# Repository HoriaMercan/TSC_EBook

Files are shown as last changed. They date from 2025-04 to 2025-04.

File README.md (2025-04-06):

## Horia Mercan - OpenBook - Systems Testing

This project presents the electronic design (schematic/pcb) and the visual design of a complete ebook. 

## Hardware Modules and Components

**ESP32-C6-WROOM-1-N8 – Main Microcontroller:**
* Power Supply: 3.3V.
* Communications: SPI, I2C, UART, GPIO.

We will link interfaces of each module with main controller's pins:

**SPI ESD Protection Lines**
* Protects the SPI lines for the SD card, e-paper, external flash.

**LDO Voltage Regulator**
* Steps down the voltage from 5V to 3.3V to power the ESP32-C6 and other modules.

**SD Card Module**
* Interface: SPI
* Pins Used:
    * `SS_SD` → `IO4`
    * `MOSI` → `IO7`
    * `MISO` → `IO2`
    * `SCK` → `IO6`

**E-Paper Display**
* Interface: SPI
* Pins Used:
    * `EPD_CS` → `IO10`
    * `EPD_DC` → `IO5`
    * `EPD_RST` → `IO23`
    * `EPD_BUSY` → `IO3`
    * `MOSI`, `SCK` (shared with SD)

**RTC Module - DS3231SN**
* Interface: I2C
* Pins Used:
    * `SCL` → `IO22`
    * `SDA` → `IO21`
    * `INT_RTC` → `IO8`
    * `32KHZ` → `IO1`
    * `RTC_RST` → `IO18`

**LiPo Fuel Gauger**
* Built-in charging control.
* MAX17048G+T10
* Battery level monitoring with:
    * Battery ChargeLevel IC → I2C => `SDA`, `SCL`

**Qwiic / Stemma QT Connector**
* Communicates entirely via I2C: `SCL`/`SDA` 

**Environmental Sensor - BME688**
* Protocol: I2C (shared) => `SDA`, `SCL`

**Environmental Sensor - BME688**
* Interface: I2C (shared with RTC)
* Power Supply: 3.3V
* Pins Used:  `SDA`, `SCL`

**External Flash - NORFlash64MB**
* Interface: SPI
* Pins Used:
    * `FLASH_CS` → `IO11`
    * Rest (`MOSI`, `MISO`, `SCK`) shared

**SD/USB interface**
* `USB_D+` → `IO13`
* `USB_D-` → `IO12`

**Reset and Boot Buttons**
* `IO/BOOT` → `IO9`
* `RESET` → `EN`

**Diodes for reverse polarity protection.**

**USB-C Connector + ESD Protection**
* Main power and data input.
* Includes TVS diodes for ESD protection.

## Block components & schematic

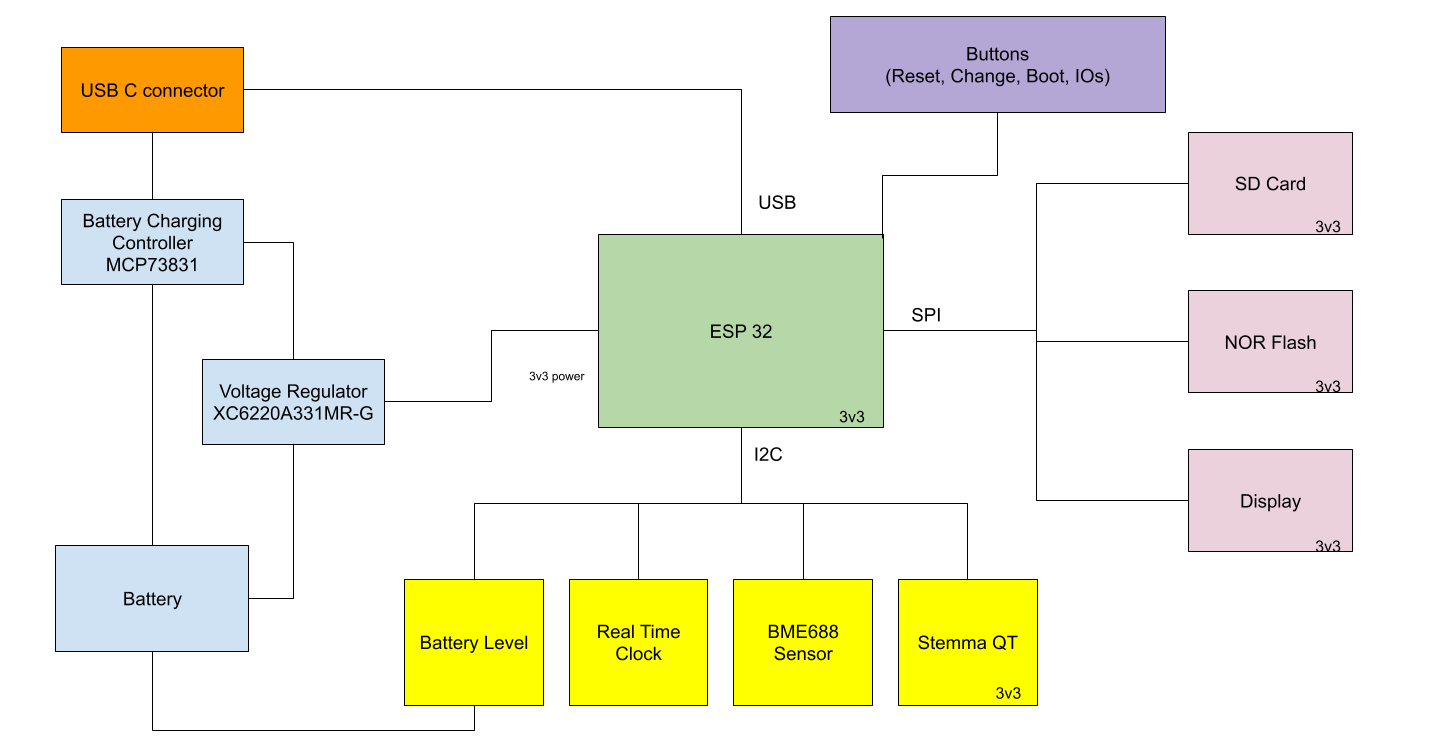
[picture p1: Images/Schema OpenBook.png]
Block functionalities and components for OpenBook


## Communication Interfaces

| Interface | Connected Components | ESP32-C6 Pins |
| :--- | :--- | :--- |
| SPI | SD Card, E-paper, NOR Flash | `MOSI` (`IO7`), `MISO` (`IO2`), `SCK` (`IO6`) |
| I2C | RTC, BME688, Battery Level | `SDA` (`IO22`), `SCL` (`IO21`) |
| UART | Debugging / Flash | `TX` (`GPIO16`), `RX` (`GPIO17`) |
| GPIO | Buttons, status signals | `IO0` - `IO23` |
| USB | PC connection / power | `USB_D+`/`D-` (`IO13`/`IO12`)

## Energy management

| Component | Power Supply (V) | Estimated Current (mA) | Estimated Power (W) | Notes |
|---|---|---|---|---|
| ESP32-C6-WROOM-1-N8 | 3.3 | 150 (average) | 0.5 | Active mode; varies significantly based on usage. |
| SD Card Module | 3.3 | 10 (average) | 0.033 | Intermittent read/write operations. |
| E-Paper Display | 3.3 | 1(average) | 0.0033 | Power used only during updates, very low average. |
| RTC Module - DS3231SN | 3.3 | 1 | 0.0033 | |
| LiPo Fuel Gauger (MAX17048) | 3.3 | 0.05 | 0.000165 | Very low power consumption. |
| BME688 (Environmental Sensor) | 3.3 | 1 (average) | 0.0033 | Intermittent readings. |
| NORFlash64MB (External Flash)| 3.3 | 2 (average) | 0.0066 | Intermittent read/write operations. |
| LDO Voltage Regulator | 5 (input) / 3.3 (output) | Variable | Variable | Efficiency depends on load; quiescent current is very low. |
| USB-C Connector + ESD | 5 (input) | Variable | Variable | Power depends on charging current; ESD protection negligible. |
| Reset/Boot Buttons | N/A | Negligible | Negligible | |
| **Total (Approximate)** | | 150-200 | **~0.55** | This is a rough estimate; actual power depends on duty cycles and usage. |

## Images

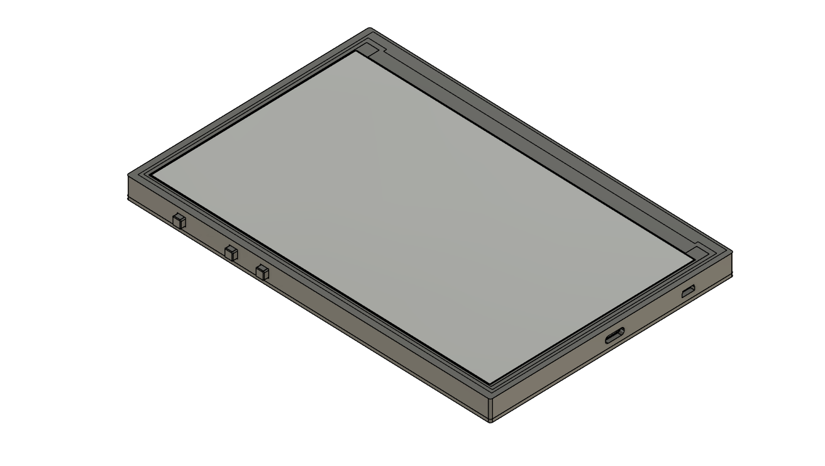
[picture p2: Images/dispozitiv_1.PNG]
Device

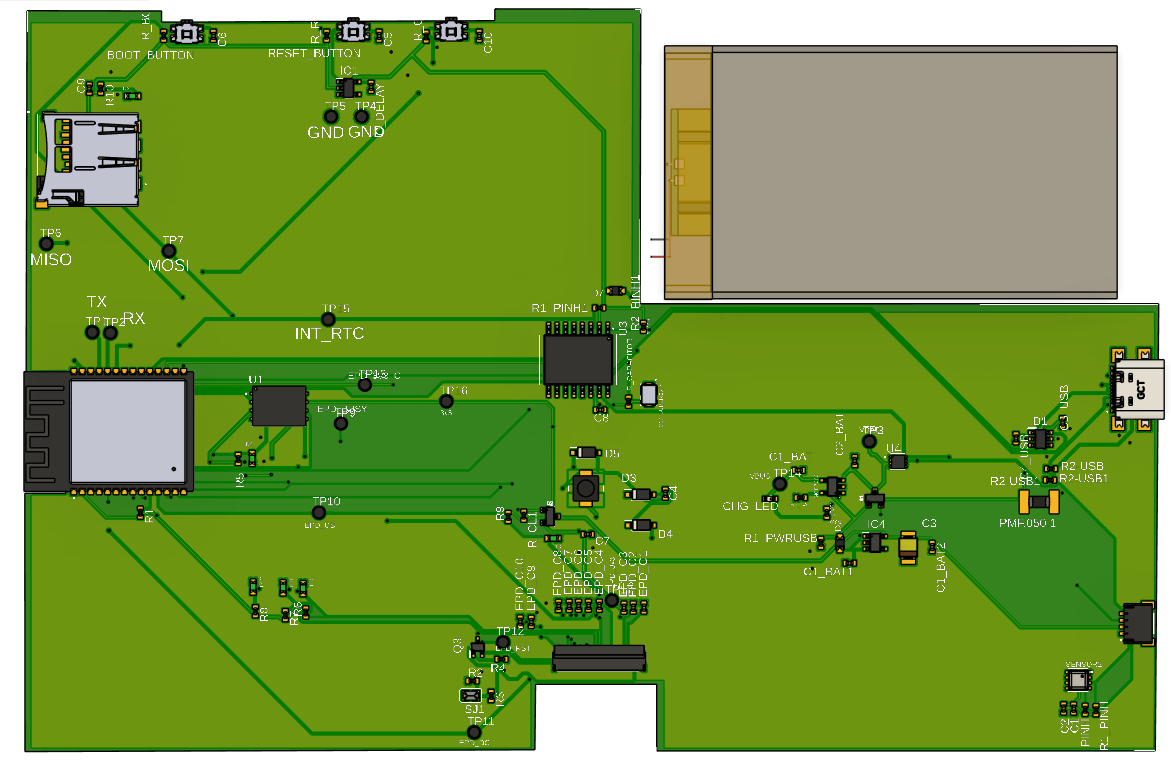
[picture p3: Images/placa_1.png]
PCB


# BOM

| Piece Name | Piece Type | Link |
|---|---|---|
| SAMACSYS_PARTS_USB4110-GF-A | USB-C Connector | https://www.snapeda.com/parts/USB4110-GF-A./Global%20Connector%20Technology/view-part/ |
| ESP32_WROVER_EAGLE-LTSPICE_R | Resistor | https://componentsearchengine.com/part-view/R0402%201%25%20100%20K%20(RC0402FR-07100KL)/YAGEO |
| MAX17048G+T10 | Cell Fuel Gauge | https://www.snapeda.com/parts/MAX17048G+T10/Analog%20Devices/view-part/ |
| W25Q512JVEIQ | Flash Memory (NOR) | https://www.snapeda.com/parts/W25Q512JVEIQ/Winbond%20Electronics/view-part/?ref=search&t=W25Q512JVEIQ |
| RCL_CPOL-EU | Polarized Capacitor | https://grabcad.com/library/tantalum-smd-capacitor-type-b-3528-1 |
| ESP32-C6-WROOM-1-N8 | ESP32 Module | https://www.snapeda.com/parts/ESP32-C6-WROOM-1-N8/Espressif%20Systems/view-part/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 |
| ADAFRUIT_CHIP-LED0603 | LED | https://www.snapeda.com/parts/KP-1608SURCK/Kingbright/view-part/?ref=search&t=LED%200603 |
| ESP32_WROVER_SPARKFUN-IC-POWER_MCP73831 | Li-Ion/Li-Poly Charge Management Controller | https://componentsearchengine.com/part-view/MCP73831T-2ACI%2FOT/Microchip |
| ESP32_WROVER_BME680_BME680 | Environmental Sensor | https://www.snapeda.com/parts/BME680/Bosch%20Sensortec/view-part/?ref=search&t=bme680 |
| CPH3225A | Crystal | https://www.snapeda.com/parts/CPH3225A/Seiko/view-part/ |
| BUTTON_CUSYOMV1 | Button | https://ro.mouser.com/ProductDetail/Panasonic/EVQ-P7L01P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. |
| FH34SRJ-24S-0.5SH_99_ | FPC Connector | https://componentsearchengine.com/part-view/FH34SRJ-24S-0.5SH(99)/Hirose |
| 744043680 | Inductor | https://eu.mouser.com/ProductDetail/Wurth-Elektronik/744043680?qs=PGXP4M47uW6VkZq%252BkzjrHA%3D%3D |
| PGB1010603MR | TVS Diode (0603) | https://www.snapeda.com/parts/PGB1010603MR/Littelfuse/view-part/ |
| SJ | 3-Way Solder Jumper | https://grabcad.com/library/solder-jumpers-1 |
| XC6220A331MR-G | Voltage Regulator | https://ro.mouser.com/ProductDetail/Torex-Semiconductor/XC6220A331MR-G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 |
| QWIIC_CONNECTOR | I²C Connector (PRT-14417) | https://www.snapeda.com/parts/PRT-14417/SparkFun/view-part/ |
| ESP32-CAP C0402 | Capacitor | https://componentsearchengine.com/part-view/CC0402MRX5R5BB106/YAGEO |
| ESP VARSISTOR | Varistor (B72520T0350K062) | https://ro.mouser.com/ProductDetail/EPCOS-TDK/B72520T0350K062?qs=dEfas%2FXlABIszF52uu7vrg%3D%3D |
| MBR0530 | Schottky Diode | https://www.snapeda.com/parts/MBR0530/Onsemi/view-part/ |
| ESP32_WROVER_SPARKFUN-DISCRETESEMI_MOSFET_PCH | MOSFET (DMG2305UX-7) | https://componentsearchengine.com/part-view/DMG2305UX-7/Diodes%20Incorporated |
| 112ATAARR03 | microSD | https://www.snapeda.com/parts/112A-TAAR-R03/Attend/view-part/ |
| ESP32_WROVER_AVX---SD0805S020S1R0 | Schottky Diode | https://componentsearchengine.com/part-view/SD0805S020S1R0/Kyocera%20AVX |
| DS3231SN# | I²C-Integrated RTC/TCXO/Crystal | https://www.snapeda.com/parts/DS3231SN%23/Analog%20Devices/view-part/?ref=search&t=DS3231SN%23 |
| BD5229G-TR | Voltage Detector | https://www.snapeda.com/parts/BD5229G-TR/Rohm/view-part/?ref=search&t=BD5229G-TR |
| SI1308EDL-T1-GE3 | MOSFET Transistor | https://www.snapeda.com/parts/SI1308EDL-T1-GE3/Vishay/view-part/ |
| TP | Test Pad | none |
| USBLC6-2SC6Y | TVS Diode | https://www.snapeda.com/parts/USBLC6-2SC6Y/STMicroelectronics/view-part/?ref=dk&t=USBLC6-2SC6Y&con_ref=None |

# ESP32 Pins Usage

**ESP32-C6 Pins and Functions**

| Pin | Signal | Describtion |
| :--- | :--- | :--- |
| 16 | RTC\_RST | RTC Reset |
| 17 | I2C\_PW | I2C Power Supply |
| 18 | EPD\_3V3\_C | 3.3V to EPD |
| 19 | SDA | I2C Data Line |
| 20 | SCL | I2C Clock Line |
| 21 | EPD\_RST | EPD (E-paper display) Reset |
| 23 | IO/CHANGE | State Change Signal |
| 24 | RX | UART Receive Line |
| 25 | TX | UART Transmit Line |
| 26 | EPD\_BUSY | EPD  Status |
| 27 | MISO | SPI Controller In Peripheral Out Line |
| 3 | RESET | Reset Circuit |
| 4 | SS\_SD | SD Card Chip Select |
| 5 | EPD\_DC | EPD (E-paper display) Data/Command Pin |
| 6 | SCK | SPI Clock Line |
| 7 | MOSI | SPI Controller Out Peripheral In Line |
| 8 | INT\_RTC | RTC Interrupt Signal |
| 9 | 32KHZ | 32 kHz Oscillator |
| 11 | IO10 | GPIO |
| 12 | IO11 | GPIO |
| 13 | IO12 | GPIO |
| 14 | IO13 | GPIO |
| 15 | IO/BOOT | Boot/Flash Button |

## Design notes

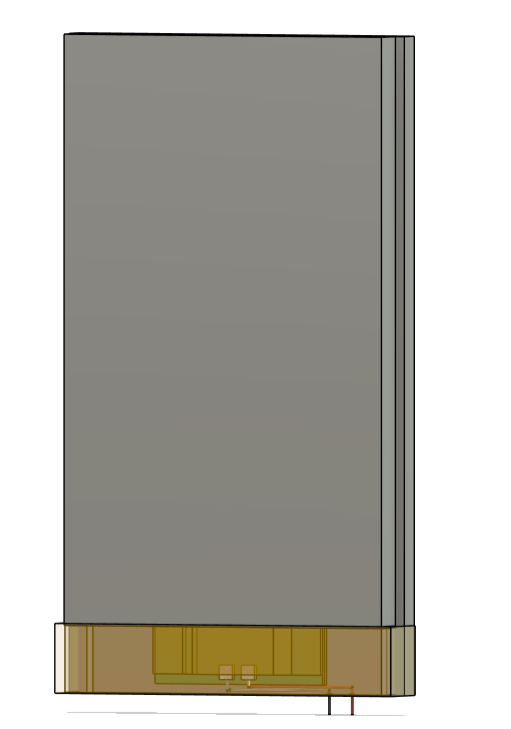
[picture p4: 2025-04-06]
Images/battery.PNG

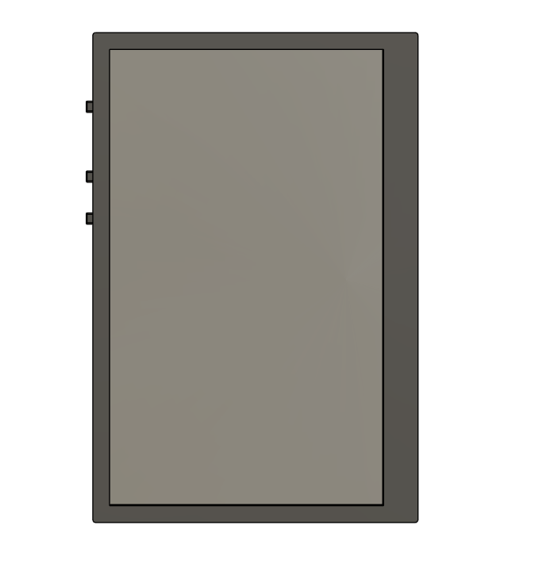
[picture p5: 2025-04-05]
Images/dispozitiv_2.PNG

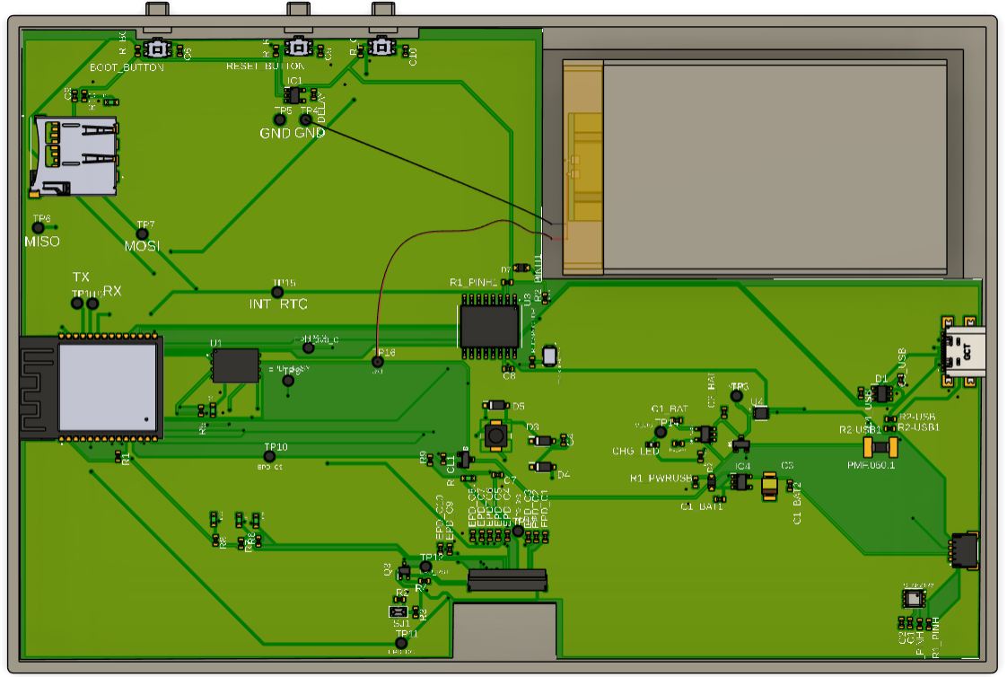
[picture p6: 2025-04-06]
Images/battery&pcb.PNG

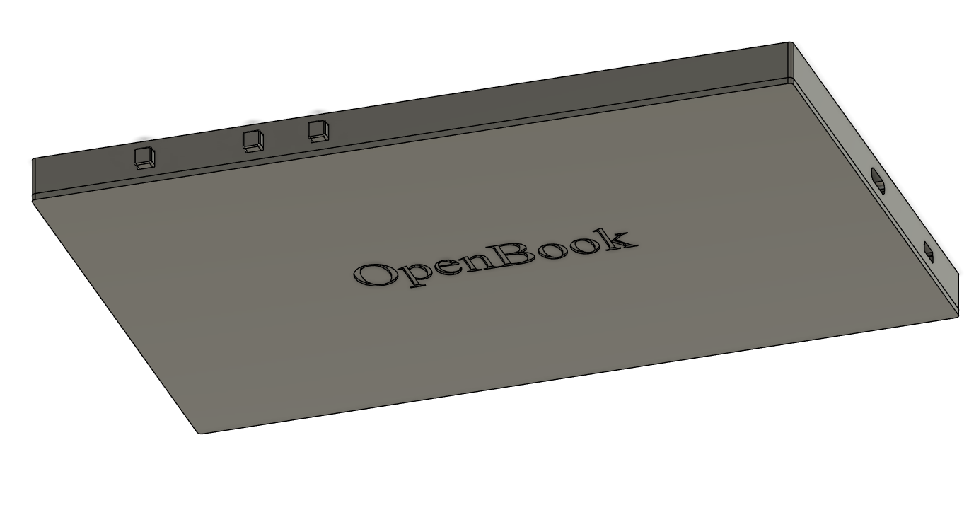
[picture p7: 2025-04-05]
Images/dispozitiv_3.PNG

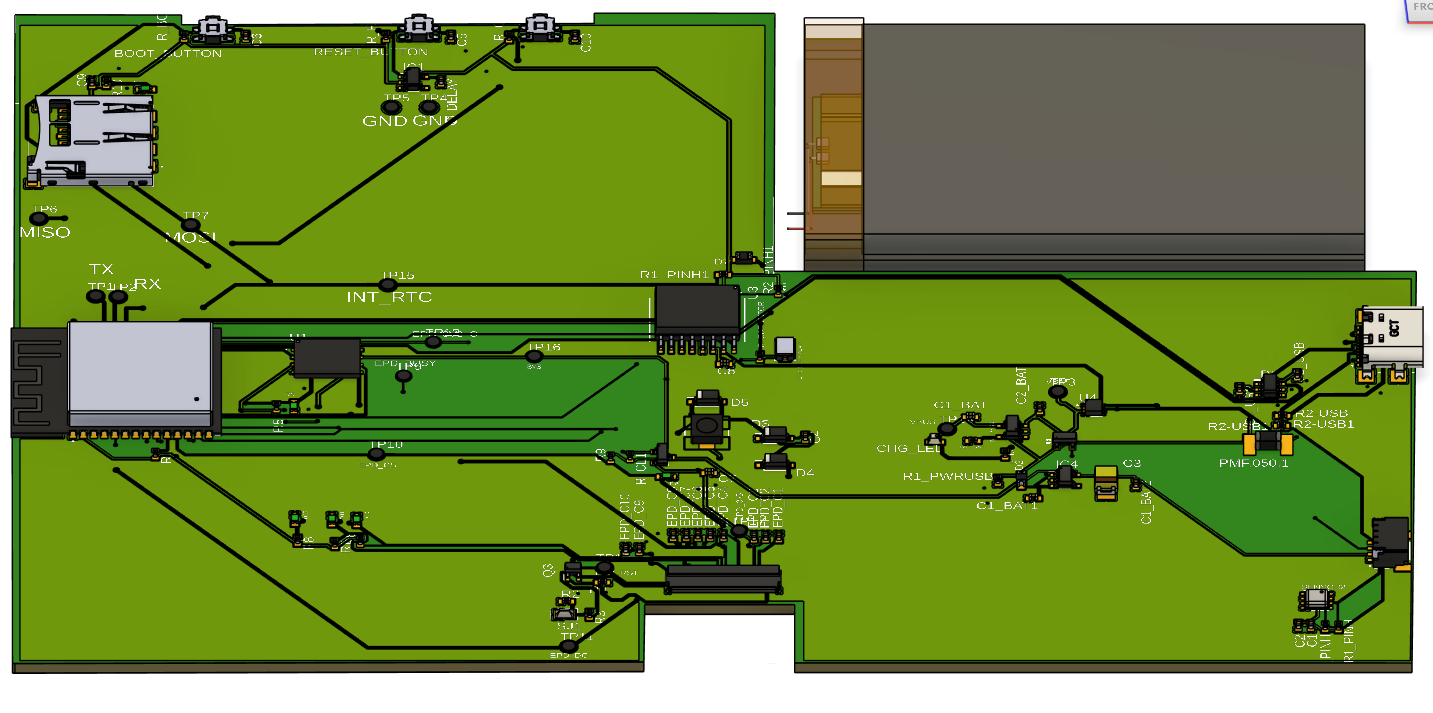
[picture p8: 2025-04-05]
Images/placa_2.PNG

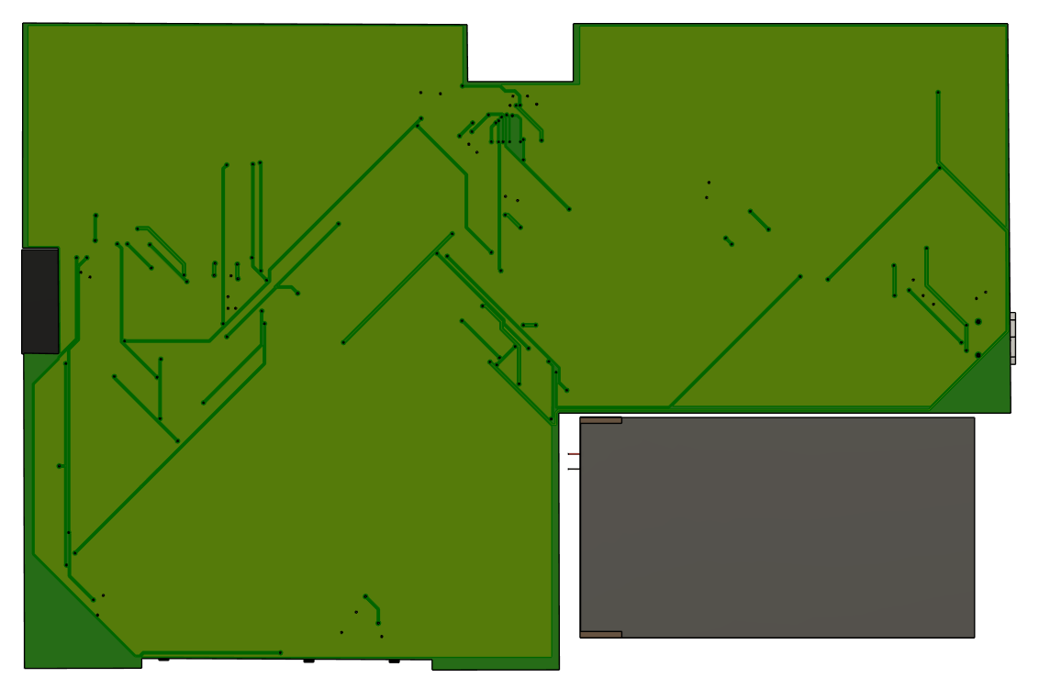
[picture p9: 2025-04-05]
Images/placa_3.PNG

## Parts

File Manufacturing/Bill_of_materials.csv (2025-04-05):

Qty | Value | Device | Package | Parts | Description | ARROW_PART_NUMBER | ARROW_PRICE-STOCK | AVAILABILITY | CENTROID_NOT_SPECIFIED | CHECK_PRICES | COPYRIGHT | DATASHEET | DESCRIPTION | DIGIKEY_DESCRIPTION | DIGIKEY_PART_NUMBER | HEIGHT | LEAD_FREE | MANUFACTURER_NAME | MANUFACTURER_PART_NUMBER | MF | MFR_NAME | MOUSER_PART_NUMBER | MOUSER_PRICE-STOCK | MOUSER_TESTING_PART_NUMBER | MOUSER_TESTING_PRICE-STOCK | MP | MPN | PACKAGE | POPULARITY | PREFIX | PRICE | PROD_ID | PURCHASE-URL | ROHS | SNAPEDA_LINK | SPICEMODEL | SPICEPREFIX | TEMPERATURE_RANGE_HIGH | TEMPERATURE_RANGE_LOW | TP_SIGNAL_NAME | VALUE
1 |  | ADAFRUIT_LEDCHIP-LED0603 | ADAFRUIT_CHIP-LED0603 | CHG_LED | LED
1 |  | SJ | SJ | SJ1 | SMD solder JUMPER |  |  |  |  |  |  |  |  |  |  |  |  |  |  |  |  |  |  |  |  |  |  |  | 3
1 | 0.47 | ESP32_WROVER_EAGLE-LTSPICE_RR0402 | ESP32_WROVER_EAGLE-LTSPICE_R0402 | R3 | RESISTOR, European symbol |  |  |  |  |  |  |  |  |  |  |  |  |  |  |  |  |  |  |  |  |  |  |  |  |  |  |  |  |  |  | NONE | R
1 | 100K | ESP32_WROVER_EAGLE-LTSPICE_RR0402 | ESP32_WROVER_EAGLE-LTSPICE_R0402 | R1_PWRUSB | RESISTOR, European symbol |  |  |  |  |  |  |  |  |  |  |  |  |  |  |  |  |  |  |  |  |  |  |  |  |  |  |  |  |  |  | NONE | R
5 | 100nF | EAGLE-LTSPICE_CC0402 | EAGLE-LTSPICE_C0402 | C4_USB, C6, C8, C9, C10 | CAPACITOR, European symbol |  |  |  |  |  |  |  |  |  |  |  |  |  |  |  |  |  |  |  |  |  |  |  |  |  |  |  |  |  |  | NONE | C
3 | 100nF | ESP32_WROVER_EAGLE-LTSPICE_CC0402 | EAGLE-LTSPICE_C0402 | C1, C2, C_DELAY | CAPACITOR, European symbol |  |  |  |  |  |  |  |  |  |  |  |  |  |  |  |  |  |  |  |  |  |  |  |  |  |  |  |  |  |  | NONE | C
1 | 100uF | RCL_CPOL-EUCT3528 | RCL_CT3528 | C3 | POLARIZED CAPACITOR, European symbol |  |  |  |  |  |  |  |  |  |  |  |  |  |  |  |  |  |  |  |  |  |  |  | 0 |  |  |  |  |  |  |  | C
16 | 10K | ESP32_WROVER_EAGLE-LTSPICE_RR0402 | ESP32_WROVER_EAGLE-LTSPICE_R0402 | R1, R1_PINH, R1_PINH1, R2_PINH, R2_PINH1, R4, R5, R6, R7, R8, R9, R10, R_BOOT, R_CHANGE, R_CL1, R_RESET | RESISTOR, European symbol |  |  |  |  |  |  |  |  |  |  |  |  |  |  |  |  |  |  |  |  |  |  |  |  |  |  |  |  |  |  | NONE | R
1 | 10uF | EAGLE-LTSPICE_CC0402 | EAGLE-LTSPICE_C0402 | C7 | CAPACITOR, European symbol |  |  |  |  |  |  |  |  |  |  |  |  |  |  |  |  |  |  |  |  |  |  |  |  |  |  |  |  |  |  | NONE | C
1 | 112A-TAAR-R03_ATTEND | 112A-TAAR-R03_ATTEND | 112ATAARR03ATTEND | J4 | Micro SD Card Socket, Push-Push Type, Top Mount, SMT, H=1.83mm, 10u |  |  |  |  |  |  |  | Micro SD Card Socket | Push-Push Type | Top Mount | SMT | H=1.83mm | 10u |  |  | 1.9mm |  | ATTEND | 112A-TAAR-R03 ATTEND
1 | 15 | ESP32_WROVER_EAGLE-LTSPICE_RR0402 | ESP32_WROVER_EAGLE-LTSPICE_R0402 | R_CAPACITOR | RESISTOR, European symbol |  |  |  |  |  |  |  |  |  |  |  |  |  |  |  |  |  |  |  |  |  |  |  |  |  |  |  |  |  |  | NONE | R
1 | 1uF | EAGLE-LTSPICE_CC0402 | EAGLE-LTSPICE_C0402 | C5 | CAPACITOR, European symbol |  |  |  |  |  |  |  |  |  |  |  |  |  |  |  |  |  |  |  |  |  |  |  |  |  |  |  |  |  |  | NONE | C
10 | 1uF/50V | ESP32_WROVER_EAGLE-LTSPICE_CC0402 | EAGLE-LTSPICE_C0402 | EPD_C1, EPD_C2, EPD_C3, EPD_C4, EPD_C5, EPD_C6, EPD_C7, EPD_C8, EPD_C9, EPD_C10 | CAPACITOR, European symbol |  |  |  |  |  |  |  |  |  |  |  |  |  |  |  |  |  |  |  |  |  |  |  |  |  |  |  |  |  |  | NONE | C
1 | 2.2 | ESP32_WROVER_EAGLE-LTSPICE_RR0402 | ESP32_WROVER_EAGLE-LTSPICE_R0402 | R2 | RESISTOR, European symbol |  |  |  |  |  |  |  |  |  |  |  |  |  |  |  |  |  |  |  |  |  |  |  |  |  |  |  |  |  |  | NONE | R
1 | 200 | ESP32_WROVER_EAGLE-LTSPICE_RR0402 | ESP32_WROVER_EAGLE-LTSPICE_R0402 | R1_BAT | RESISTOR, European symbol |  |  |  |  |  |  |  |  |  |  |  |  |  |  |  |  |  |  |  |  |  |  |  |  |  |  |  |  |  |  | NONE | R
2 | 20V/4.2A/52mO/1.4W | ESP32_WROVER_SPARKFUN-DISCRETESEMI_MOSFET_PCH-DMG2305UX-7 | ESP32_WROVER_SPARKFUN-DISCRETESEMI_SOT23-3 | Q1, Q2 | P-channel MOSFETs |  |  |  |  |  |  |  |  |  |  |  |  |  |  |  |  |  |  |  |  |  |  |  |  |  |  | TRAN-14388 |  |  |  |  |  |  |  |  | 20V/4.2A/52mO/1.4W
1 | 2K | ESP32_WROVER_EAGLE-LTSPICE_RR0402 | ESP32_WROVER_EAGLE-LTSPICE_R0402 | R2_BAT | RESISTOR, European symbol |  |  |  |  |  |  |  |  |  |  |  |  |  |  |  |  |  |  |  |  |  |  |  |  |  |  |  |  |  |  | NONE | R
3 | 4.7uF | EAGLE-LTSPICE_CC0402 | EAGLE-LTSPICE_C0402 | C1_BAT1, C1_BAT2, C5_USB | CAPACITOR, European symbol |  |  |  |  |  |  |  |  |  |  |  |  |  |  |  |  |  |  |  |  |  |  |  |  |  |  |  |  |  |  | NONE | C
2 | 4.7uF | ESP32_WROVER_EAGLE-LTSPICE_CC0402 | EAGLE-LTSPICE_C0402 | C1_BAT, C2_BAT | CAPACITOR, European symbol |  |  |  |  |  |  |  |  |  |  |  |  |  |  |  |  |  |  |  |  |  |  |  |  |  |  |  |  |  |  | NONE | C
1 | 4.7uF/25V | EAGLE-LTSPICE_CC0402 | EAGLE-LTSPICE_C0402 | C4 | CAPACITOR, European symbol |  |  |  |  |  |  |  |  |  |  |  |  |  |  |  |  |  |  |  |  |  |  |  |  |  |  |  |  |  |  | NONE | C
2 | 5k1 | ESP32_WROVER_EAGLE-LTSPICE_RR0402 | ESP32_WROVER_EAGLE-LTSPICE_R0402 | R2-USB, R2-USB1 | RESISTOR, European symbol |  |  |  |  |  |  |  |  |  |  |  |  |  |  |  |  |  |  |  |  |  |  |  |  |  |  |  |  |  |  | NONE | R
1 | 744043680IND_4828-WE-TPC_WRE | 744043680IND_4828-WE-TPC_WRE | IND_4828-WE-TPC_WRE | L1 |  |  |  |  |  |  | Copyright (C) 2024 Ultra Librarian. All rights reserved. |  |  |  |  |  |  |  | 744043680 |  | Wurth Electronics
1 | BD5229G-TR | BD5229G-TR | SOT95P280X125-5N | IC1 | Voltage Detector with Adjustable Delay Time: CMOS processes are utilized to develop high precision, low current consumption CMOS reset ICs that allow arbitrary setting of the delay time. The extensive lineup includes both Nch Open Drain and CMOS output types in a wide range of detection voltages (from 2.3V to 6.0V, in 0.1V steps), enabling selection of the ideal solution based on customer requirements. In addition, the entire series is of course both lead-free and RoHS-compliant. |  |  |  |  |  |  |  | Voltage Detector with Adjustable Delay Time: CMOS processes are utilized to develop high precision | low current consumption CMOS reset ICs that allow arbitrary setting of the delay time. The extensive lineup includes both Nch Open Drain and CMOS output types in a wide range of detection voltages (from 2.3V to 6.0V | in 0.1V steps) | enabling selection of the ideal solution based on customer requirements. In addition | the entire series is of course both lead-free and RoHS-compliant. |  |  | 1.25mm |  | ROHM Semiconductor | BD5229G-TR |  |  | 755-BD5229G-TR | https://www.mouser.co.uk/ProductDetail/ROHM-Semiconductor/BD5229G-TR?qs=4kLU8WoGk0vvnhrrYwdszw%3D%3D
3 | BUTTON_CUSYOMV1 | BUTTON_CUSYOMV1 | MYBUTTON | BOOT_BUTTON, CHANGE_BUTTON, RESET_BUTTON
1 | CPH3225A | CPH3225A | CAPCP3225X100N | C10_SUPERCAP | Cap 0.011F 3.3V 1210 Flat Check availability |  |  | Not in stock |  | https://www.snapeda.com/parts/CPH3225A/Seiko+Instruments/view-part/?ref=eda |  |  | 11 mF (EDLC) Supercapacitor 3.3 V 1210 (3225 Metric) - - |  |  |  |  |  |  | Seiko Instruments |  |  |  |  |  | CPH3225A |  | 1210 Seiko |  |  | None |  | https://www.snapeda.com/api/url_track_click_mouser/?unipart_id=562593&manufacturer=Seiko Instruments&part_name=CPH3225A&search_term=None |  | https://www.snapeda.com/parts/CPH3225A/Seiko+Instruments/view-part/?ref=snap
1 | DS3231SN# | DS3231SN# | SOIC127P1032X265-16N | U3 | Real Time Clock Serial 16-Pin SOIC W T/R Check availability |  |  | In Stock |  | https://www.snapeda.com/parts/DS3231SN%23/Analog+Devices/view-part/?ref=eda |  |  | Extremely Accurate I²C-Integrated RTC/TCXO/Crystal |  |  |  |  |  |  | Analog Devices |  |  |  |  |  | DS3231SN# |  | SOIC-16 Maxim |  |  | None |  | https://www.snapeda.com/api/url_track_click_mouser/?unipart_id=99048&manufacturer=Analog Devices&part_name=DS3231SN#&search_term=None |  | https://www.snapeda.com/parts/DS3231SN%23/Analog+Devices/view-part/?ref=snap
1 | ESP32-C6-WROOM-1-N8 | ESP32-C6-WROOM-1-N8 | XCVR_ESP32-C6-WROOM-1-N8 | U2 | Check availability |  |  | In Stock |  | https://www.snapeda.com/parts/ESP32-C6-WROOM-1-N8/Espressif+Systems/view-part/?ref=eda |  |  | Multiprotocol Modules ESP32-C6 module | Wi-Fi 6 in 2.4 GHz band | Bluetooth 5 | Zigbee 3.0 and Thread. ESP34-WROOM Compatible - ENGINEERING SAMPLE |  |  |  |  |  |  | Espressif Systems |  |  |  |  |  | ESP32-C6-WROOM-1-N8 |  | None |  |  | None |  |  |  | https://www.snapeda.com/parts/ESP32-C6-WROOM-1-N8/Espressif+Systems/view-part/?ref=snap
1 | ESP32C6_VARISTORCN1812 | ESP32C6_VARISTORCN1812 | ESP32C6_VARISTOR_CT/CN1812 | PMF.050.1 | VARISTOR |  |  |  |  |  |  |  |  |  |  |  |  |  |  |  |  |  |  |  |  |  |  |  | 0
2 | ESP32_WROVER_AVX---SD0805S020S1R0_AVX_SD0805S020S1R0_0_0AVX_SD0805S020S1R0_0_0 | ESP32_WROVER_AVX---SD0805S020S1R0_AVX_SD0805S020S1R0_0_0AVX_SD0805S020S1R0_0_0 | ESP32_WROVER_AVX---SD0805S020S1R0_AVX_SD0805S020S1R0_0 | D2, D7 | Schottky Barrier Rectifier Diode |  |  |  | No |  |  | http://datasheets.avx.com/schottky.pdf |  | DIODE SCHOTTKY 20V 1A 0805 | 478-7800-1-ND |  | yes |  |  | AVX |  | 581-SD0805S020S1R0 |  |  |  |  |  | 0805 (2012 metric) |  | D |  |  |  | yes |  |  |  | +125°C | -55°C
1 | ESP32_WROVER_BME680_BME680 | ESP32_WROVER_BME680_BME680 | ESP32_WROVER_BME680_PSON80P300X300X100-8N | SENSOR2 | Integrated Environmental Unit |  |  | Unavailable |  |  |  |  | Integrated Environmental Unit |  |  |  |  |  |  | Bosch Sensortec |  |  |  |  |  | BME680 |  | LGA-8 Bosch Tools |  |  | None
1 | ESP32_WROVER_SPARKFUN-IC-POWER_MCP73831 | ESP32_WROVER_SPARKFUN-IC-POWER_MCP73831 | ESP32_WROVER_SPARKFUN-IC-POWER_SOT23-5 | MCP73831 | MCP73831T Li-Ion, Li-Pol Controller |  |  |  |  |  |  |  |  |  |  |  |  |  |  |  |  |  |  |  |  |  |  |  |  |  |  | IC-09995
1 | FH34SRJ-24S-0.5SH_99_ | FH34SRJ-24S-0.5SH_99_ | FH34SRJ24S05SH99 | J1 | (0.50mm) Surface Mount, Right Angle |  |  |  |  |  |  |  | 24 Position FFC | FPC Connector Contacts | (0.50mm) Surface Mount | Right Angle |  |  | 1.1mm |  | Hirose | FH34SRJ-24S-0.5SH(99) |  |  | 798-FH34SRJ24S05SH99 | https://www.mouser.co.uk/ProductDetail/Hirose-Connector/FH34SRJ-24S-0.5SH99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
1 | MAX17048G+T10 | MAX17048G+T10 | SON50P200X200X80-9N | U4 | Check availability |  |  | In Stock |  | https://www.snapeda.com/parts/MAX17048G+T10/Analog+Devices/view-part/?ref=eda |  |  | 3µA 1-Cell/2-Cell Fuel Gauge with ModelGauge |  |  |  |  |  |  | Analog Devices |  |  |  |  |  | MAX17048G+T10 |  | TDFN-8 Maxim |  |  | None |  | https://www.snapeda.com/api/url_track_click_mouser/?unipart_id=329239&manufacturer=Analog Devices&part_name=MAX17048G+T10&search_term=None |  | https://www.snapeda.com/parts/MAX17048G+T10/Analog+Devices/view-part/?ref=snap
3 | MBR0530 | MBR0530 | SOD3716X135N | D3, D4, D5 | ON SEMICONDUCTOR - MBR0530 - DIODE, SCHOTTKY, 0.5A, 30V, SOD-123 |  |  | In Stock |  | https://www.snapeda.com/parts/MBR0530/Onsemi/view-part/?ref=eda |  |  | Diode Schottky 30 V 500mA Surface Mount SOD-123 |  |  |  |  |  |  | ON Semiconductor |  |  |  |  |  | MBR0530 |  | SOD-123-2 ON Semiconductor |  |  | None |  | https://www.snapeda.com/api/url_track_click_mouser/?unipart_id=179458&manufacturer=ON Semiconductor&part_name=MBR0530&search_term=None |  | https://www.snapeda.com/parts/MBR0530/Onsemi/view-part/?ref=snap
6 | PGB1010603MR | PGB1010603MR | DIOC1608X36N | D6, D8, D9, D10, D11, D12 | Check availability |  |  | In Stock |  | https://www.snapeda.com/parts/PGB1010603MR/Littelfuse/view-part/?ref=eda |  |  | 150V (Typ) Clamp - Ipp Tvs Diode Surface Mount 0603 (1608 Metric) |  |  |  |  |  |  | Littelfuse Inc. |  |  |  |  |  | PGB1010603MR |  | 0603 Littelfuse Inc. |  |  | None |  | https://www.snapeda.com/api/url_track_click_mouser/?unipart_id=5659453&manufacturer=Littelfuse Inc.&part_name=PGB1010603MR&search_term=None |  | https://www.snapeda.com/parts/PGB1010603MR/Littelfuse/view-part/?ref=snap
1 | QWIIC_RIGHT_ANGLE | QWIIC_CONNECTORJS-1MM | JST04_1MM_RA | J3 | SparkFun I2C Standard Qwiic Connector |  |  |  |  |  |  |  |  |  |  |  |  |  |  |  |  |  |  |  |  |  |  |  |  |  |  | CONN-13694 |  |  |  |  |  |  |  |  | QWIIC_RIGHT_ANGLE
1 | SAMACSYS_PARTS_USB4110-GF-A | SAMACSYS_PARTS_USB4110-GF-A | SAMACSYS_PARTS_USB4110GFA | J2 | CONN USB 2.0 TYPE-C R/A SMT |  |  |  |  |  |  |  | CONN USB 2.0 TYPE-C R/A SMT |  |  | 3.26mm |  | GCT (GLOBAL CONNECTOR TECHNOLOGY) | USB4110-GF-A |  |  | 640-USB4110-GF-A | https://www.mouser.co.uk/ProductDetail/GCT/USB4110-GF-A?qs=KUoIvG%2F9IlYiZvIXQjyJeA%3D%3D
1 | SI1308EDL-T1-GE3 | SI1308EDL-T1-GE3 | SOT65P210X110-3N | Q3 | MOSFET N-Ch 30V 1.5A TrenchFET SC70 Vishay Si1308EDL-T1-GE3 N-channel MOSFET Transistor, 1.5 A, 30 V, 3-Pin SC-70 |  |  | In Stock |  | https://www.snapeda.com/parts/SI1308EDL-T1-GE3/Vishay+Siliconix/view-part/?ref=eda |  |  | Si1308EDL-T1-GE3 N-channel MOSFET Transistor | 1.5 A | 30 V | 3-Pin SC-70 | Siliconix / Vishay SI1308EDL-T1-GE3 |  |  |  |  |  |  | Vishay Siliconix |  |  |  |  |  | SI1308EDL-T1-GE3 |  | SOT-323 Vishay Semiconductor |  |  | None |  | https://www.snapeda.com/api/url_track_click_mouser/?unipart_id=274603&manufacturer=Vishay Siliconix&part_name=SI1308EDL-T1-GE3&search_term=None |  | https://www.snapeda.com/parts/SI1308EDL-T1-GE3/Vishay+Siliconix/view-part/?ref=snap
17 | TPTP20R | TPTP20R | TP20R | TP1, TP2, TP3, TP4, TP5, TP6, TP7, TP8, TP9, TP10, TP11, TP12, TP13, TP14, TP15, TP16, TP17 | Test pad |  |  |  |  |  |  |  |  |  |  |  |  |  |  |  |  |  |  |  |  |  |  |  | 2
1 | USBLC6-2SC6Y | USBLC6-2SC6Y | SOT95P280X145-6N | D1 | Low Cap. ESD Protection Auto SOT-23-6 STMicroelectronics USBLC6-2SC6Y, Dual Uni-Directional TVS Diode Array, 6-Pin SOT-23 |  |  | In Stock |  | https://www.snapeda.com/parts/USBLC6-2SC6Y/STMicroelectronics/view-part/?ref=eda |  |  | 17V Clamp 5A (8/20µs) Ipp Tvs Diode Surface Mount SOT-23-6 |  |  |  |  |  |  | STMicroelectronics |  |  |  |  |  | USBLC6-2SC6Y |  | SOT-23-6 STMicroelectronics |  |  | None |  |  |  | https://www.snapeda.com/parts/USBLC6-2SC6Y/STMicroelectronics/view-part/?ref=snap
1 | W25Q512JVEIQ | W25Q512JVEIQ | SON127P600X800X80-9N | U1 | Check availability |  |  | In Stock |  | https://www.snapeda.com/parts/W25Q512JVEIQ/Winbond+Electronics/view-part/?ref=eda |  |  | FLASH - NOR Memory IC 512Mb (64M x 8) SPI - Quad I/O 133 MHz 8-WSON (8x6) |  |  |  |  |  |  | Winbond Electronics |  |  |  |  |  | W25Q512JVEIQ |  | Package |  |  | None |  |  |  | https://www.snapeda.com/parts/W25Q512JVEIQ/Winbond+Electronics/view-part/?ref=snap
1 | XC6220A331MR-G | XC6220A331MR-G | SOT95P280X125-5N | IC4 | LDO Voltage Regulators |  |  |  |  |  |  |  | LDO Voltage Regulators |  |  | 1.2mm |  | Torex | XC6220A331MR-G |  |  | 865-XC6220A331MR-G | https://www.mouser.co.uk/ProductDetail/Torex-Semiconductor/XC6220A331MR-G?qs=AsjdqWjXhJ8ZSWznL1J0gg%3D%3D

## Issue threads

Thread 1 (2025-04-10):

[PCB] Board Thickness

david1203d, 2025-04-10:
Grosimea board-ului trebuie de 1mm, conform imaginii:

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

 In imaginea de mai jos se poate vedea ca grosimea este de 1.6mm

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

HoriaMercan, 2025-04-14:
Fixed in [commit-ul acesta](https://github.com/HoriaMercan/TSC_EBook/commit/b2258b8eba3d8c812f9d871648268203a0e23acc).

Closed 2025-04-14.

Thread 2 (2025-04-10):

[PCB] Silkscreen issue

fynnceapa, 2025-04-10:
Besides the test pads, no other component has its name on the silkscreen, as can be seen in the image below.

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

The silkscreen has to contain the name of the components but not their value.

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

Closed 2025-04-14.

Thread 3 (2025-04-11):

[PCB] Fragmentare plan GND

david1203d, 2025-04-11:
Planul de masa (rosu) este fragmentat in mai multe zone, in special in partea centrala si dreapta, din cauza traseelor care traverseaza planele.
Indicatie pentru rezolvare:

-  Route -> Via -> Signal Name -> Scrii GND -> Dai click-uri pe zonele albastre.

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

HoriaMercan, 2025-04-14:
Fixed in [commit-ul acesta](https://github.com/HoriaMercan/TSC_EBook/commit/b2258b8eba3d8c812f9d871648268203a0e23acc). Am adaugat Via Stitching pentru zonele fragmentate.

Closed 2025-04-14.

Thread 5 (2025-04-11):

[PCB] Masuratori lipsa

david1203d, 2025-04-11:
Conform imaginii de mai jos, ar trebui sa apara si masuratorile:

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

HoriaMercan, 2025-04-14:
Fixed in [commit-ul acesta](https://github.com/HoriaMercan/TSC_EBook/commit/b2258b8eba3d8c812f9d871648268203a0e23acc). Layer-ul care trebuia sa afiseze masuratorile era pus pe hidden.

Closed 2025-04-14.

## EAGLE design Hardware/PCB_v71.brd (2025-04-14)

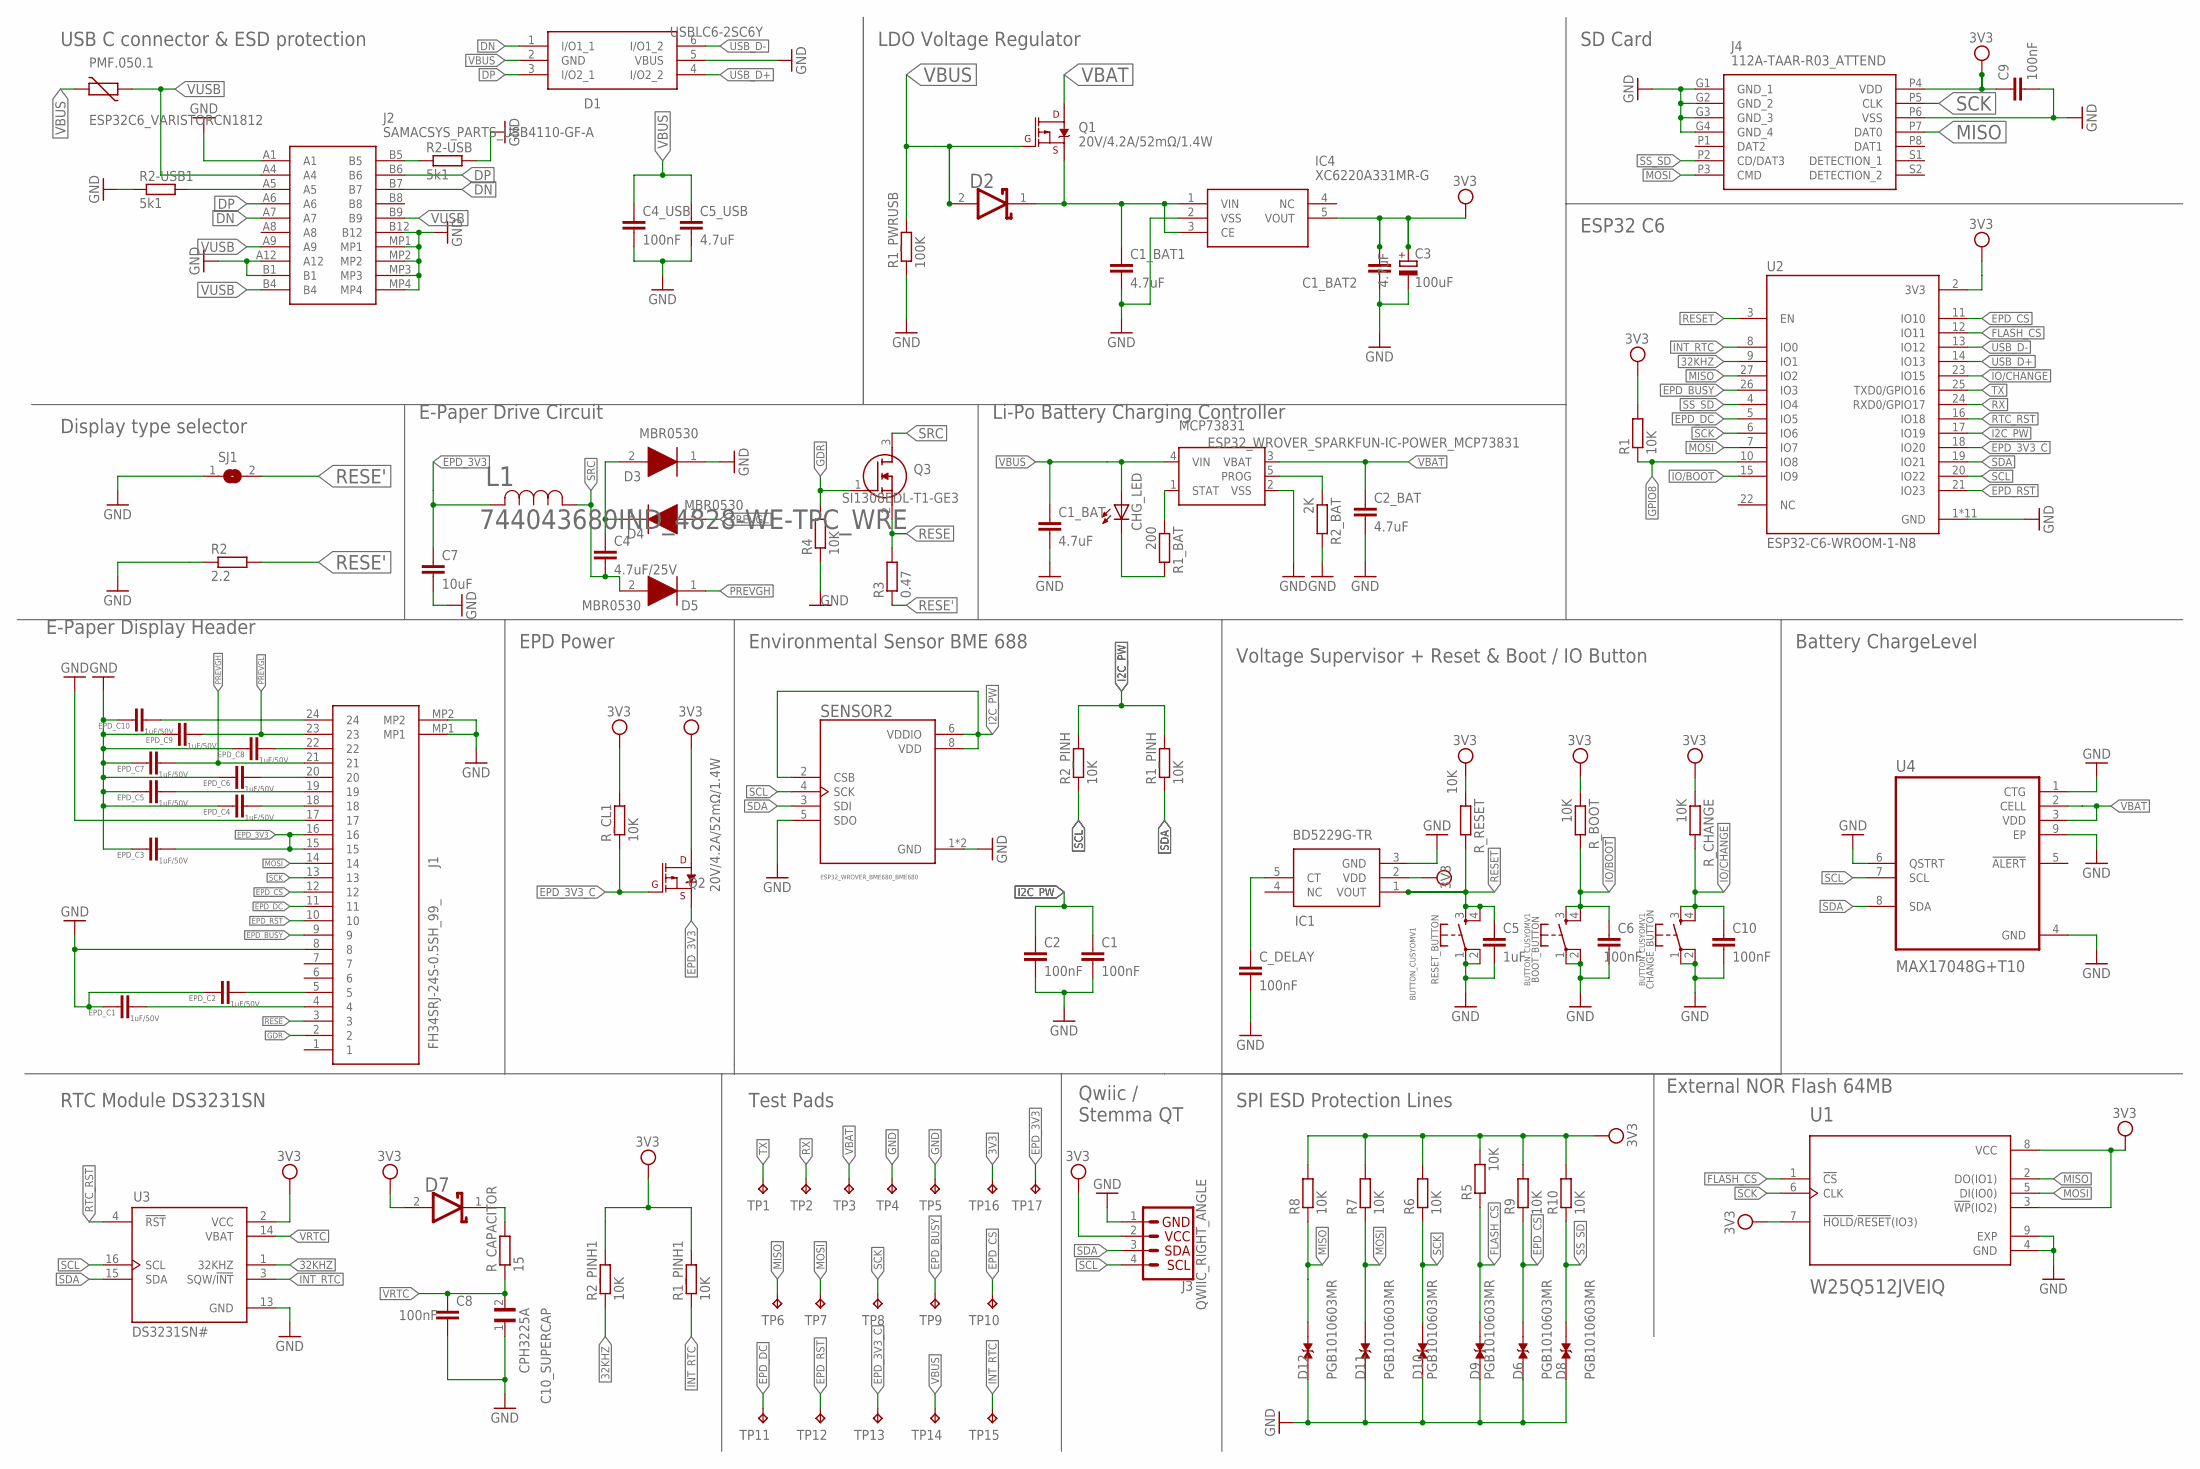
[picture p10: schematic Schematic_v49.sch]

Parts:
BOOT_BUTTON: BUTTON_CUSYOMV1; MYBUTTON
C1, C2, C4_USB, C6, C8, C9, C10: 100nF; EAGLE-LTSPICE_C0402
C1_BAT, C1_BAT1, C1_BAT2, C2_BAT, C5_USB: 4.7uF; EAGLE-LTSPICE_C0402
C3: 100uF; RCL_CT3528
C4: 4.7uF/25V; EAGLE-LTSPICE_C0402
C5: 1uF; EAGLE-LTSPICE_C0402
C7: 10uF; EAGLE-LTSPICE_C0402
C10_SUPERCAP: CPH3225A; CAPCP3225X100N
CHANGE_BUTTON: BUTTON_CUSYOMV1; MYBUTTON
CHG_LED: ADAFRUIT_LEDCHIP-LED0603; ADAFRUIT_CHIP-LED0603
C_DELAY: 100nF; EAGLE-LTSPICE_C0402
D1: USBLC6-2SC6Y; SOT95P280X145-6N
D2, D7: ESP32_WROVER_AVX---SD0805S020S1R0_AVX_SD0805S020S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; ESP32_WROVER_AVX---SD0805S020S1R0_AVX_SD0805S020S1R0_0
D3, D4, D5: MBR0530; SOD3716X135N
D6, D8, D9, D10, D11, D12: PGB1010603MR; DIOC1608X36N
EPD_C1, EPD_C2, EPD_C3, EPD_C4, EPD_C5, EPD_C6, EPD_C7, EPD_C8, EPD_C9, EPD_C10: 1uF/50V; EAGLE-LTSPICE_C0402
IC1: BD5229G-TR; SOT95P280X125-5N
IC4: XC6220A331MR-G; SOT95P280X125-5N
J1: FH34SRJ-24S-0.5SH_99_; FH34SRJ24S05SH99
J2: SAMACSYS_PARTS_USB4110-GF-A; SAMACSYS_PARTS_USB4110GFA
J3: QWIIC_RIGHT_ANGLE; JST04_1MM_RA
J4: 112A-TAAR-R03_ATTEND; 112ATAARR03ATTEND
L1: 744043680IND_4828-WE-TPC_WRE; IND_4828-WE-TPC_WRE
MCP73831: ESP32_WROVER_SPARKFUN-IC-POWER_MCP73831; ESP32_WROVER_SPARKFUN-IC-POWER_SOT23-5
PMF.050.1: ESP32C6_VARISTORCN1812; ESP32C6_VARISTOR_CT/CN1812
Q1, Q2: 20V/4.2A/52mΩ/1.4W; ESP32_WROVER_SPARKFUN-DISCRETESEMI_SOT23-3
Q3: SI1308EDL-T1-GE3; SOT65P210X110-3N
R1, R1_PINH, R1_PINH1, R2_PINH, R2_PINH1, R4, R5, R6, R7, R8, R9, R10: 10K; ESP32_WROVER_EAGLE-LTSPICE_R0402
R1_BAT: 200; ESP32_WROVER_EAGLE-LTSPICE_R0402
R1_PWRUSB: 100K; ESP32_WROVER_EAGLE-LTSPICE_R0402
R2: 2.2; ESP32_WROVER_EAGLE-LTSPICE_R0402
R2-USB, R2-USB1: 5k1; ESP32_WROVER_EAGLE-LTSPICE_R0402
R2_BAT: 2K; ESP32_WROVER_EAGLE-LTSPICE_R0402
R3: 0.47; ESP32_WROVER_EAGLE-LTSPICE_R0402
RESET_BUTTON: BUTTON_CUSYOMV1; MYBUTTON
R_BOOT: 10K; ESP32_WROVER_EAGLE-LTSPICE_R0402
R_CAPACITOR: 15; ESP32_WROVER_EAGLE-LTSPICE_R0402
R_CHANGE: 10K; ESP32_WROVER_EAGLE-LTSPICE_R0402
R_CL1: 10K; ESP32_WROVER_EAGLE-LTSPICE_R0402
R_RESET: 10K; ESP32_WROVER_EAGLE-LTSPICE_R0402
SENSOR2: ESP32_WROVER_BME680_BME680; ESP32_WROVER_BME680_PSON80P300X300X100-8N
SJ1: SJ
TP1, TP2, TP3, TP4, TP5, TP6, TP7, TP8, TP9, TP10, TP11, TP12, TP13, TP14, TP15, TP16, TP17: TPTP20R; TP20R
U1: W25Q512JVEIQ; SON127P600X800X80-9N
U2: ESP32-C6-WROOM-1-N8; XCVR_ESP32-C6-WROOM-1-N8
U3: DS3231SN#; SOIC127P1032X265-16N
U4: MAX17048G+T10; SON50P200X200X80-9N

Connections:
3V3: C1_BAT2.1, C3.+, C9.1, D7.2 (ANODE), IC1.2 (VDD), IC4.5 (VOUT), J3.2, J4.P4 (VDD), Q2.3 (D), R1.2, R1_PINH1.2, R2_PINH1.2, R5.2, R6.2, R7.2, R8.2, R9.2, R10.2, R_BOOT.1, R_CHANGE.1, R_CL1.2, R_RESET.1, TP16.TP, U1.3 (!WP!(IO2)), U1.7 (!HOLD!/!RESET!(IO3)), U1.8 (VCC), U2.2 (3V3), U3.2 (VCC)
32KHZ: R2_PINH1.1, U2.9 (IO1), U3.1 (32KHZ)
DN: D1.1 (I/O1_1), J2.A7, J2.B7
DP: D1.3 (I/O2_1), J2.A6, J2.B6
EPD_3V3: C7.1, EPD_C3.2, J1.15, J1.16, L1.2, Q2.2 (S), TP17.TP
EPD_3V3_C: Q2.1 (G), R_CL1.1, TP13.TP, U2.18 (IO20)
EPD_BUSY: J1.9, TP9.TP, U2.26 (IO3)
EPD_CS: D6.2, J1.12, R9.1, TP10.TP, U2.11 (IO10)
EPD_DC: J1.11, TP11.TP, U2.5 (IO5)
EPD_RST: J1.10, TP12.TP, U2.21 (IO23)
FLASH_CS: D9.2, R5.1, U1.1 (!CS), U2.12 (IO11)
GDR: J1.2, Q3.1 (G), R4.2
GND: BOOT_BUTTON.1, BOOT_BUTTON.2, C1.2, C1_BAT.2, C1_BAT1.2, C1_BAT2.2, C2.2, C2_BAT.2, C3.-, C4_USB.2, C5.2, C5_USB.2, C6.2, C7.2, C8.2, C9.2, C10.2, C10_SUPERCAP.1, CHANGE_BUTTON.1, CHANGE_BUTTON.2, C_DELAY.2, D1.5 (VBUS), D3.1 (K), D6.1, D8.1, D9.1, D10.1, D11.1, D12.1, EPD_C1.1, EPD_C2.1, EPD_C3.1, EPD_C4.1, EPD_C5.1, EPD_C6.1, EPD_C7.1, EPD_C8.1, EPD_C9.1, EPD_C10.1, IC1.3 (GND), IC4.2 (VSS), J1.8, J1.17, J1.MP1, J1.MP2, J2.A1, J2.A12, J2.B1, J2.B12, J2.MP1, J2.MP2, J2.MP3, J2.MP4, J3.1, J4.G1 (GND_1), J4.G2 (GND_2), J4.G3 (GND_3), J4.G4 (GND_4), J4.P6 (VSS), MCP73831.2 (VSS), R1_PWRUSB.1, R2.1, R2-USB.2, R2-USB1.1, R2_BAT.2, R4.1, RESET_BUTTON.1, RESET_BUTTON.2, SENSOR2.1 (GND), SENSOR2.5 (SDO), SENSOR2.7 (GND), SJ1.1, TP4.TP, TP5.TP, U1.4 (GND), U1.9 (EXP), U2.1 (GND), U2.28 (GND), U2.29_1 (GND), U2.29_2 (GND), U2.29_3 (GND), U2.29_4 (GND), U2.29_5 (GND), U2.29_6 (GND), U2.29_7 (GND), U2.29_8 (GND), U2.29_9 (GND), U3.13 (GND), U4.1 (CTG), U4.4 (GND), U4.6 (QSTRT), U4.9 (EP)
GPIO8: R1.1, U2.10 (IO8)
I2C_PW: C1.1, C2.1, R1_PINH.2, R2_PINH.2, SENSOR2.2 (CSB), SENSOR2.6 (VDDIO), SENSOR2.8 (VDD), U2.17 (IO19)
INT_RTC: R1_PINH1.1, TP15.TP, U2.8 (IO0), U3.3 (SQW/!INT)
IO/BOOT: BOOT_BUTTON.3, BOOT_BUTTON.4, C6.1, R_BOOT.2, U2.15 (IO9)
IO/CHANGE: C10.1, CHANGE_BUTTON.3, CHANGE_BUTTON.4, R_CHANGE.2, U2.23 (IO15)
MISO: D12.2, J4.P7 (DAT0), R8.1, TP6.TP, U1.2 (DO(IO1)), U2.27 (IO2)
MOSI: D11.2, J1.14, J4.P3 (CMD), R7.1, TP7.TP, U1.5 (DI(IO0)), U2.7 (IO7)
unnamed: J2.A5, R2-USB1.2
unnamed: J2.B5, R2-USB.1
unnamed: D7.1 (CATHODE), R_CAPACITOR.2
unnamed: C1_BAT1.1, D2.1 (CATHODE), IC4.1 (VIN), IC4.3 (CE), Q1.2 (S)
unnamed: C4.1, D3.2 (A), D4.1 (K)
unnamed: CHG_LED.C, R1_BAT.2
unnamed: MCP73831.1 (STAT), R1_BAT.1
unnamed: EPD_C2.2, J1.5
unnamed: MCP73831.5 (PROG), R2_BAT.1
unnamed: EPD_C1.2, J1.4
unnamed: C_DELAY.1, IC1.5 (CT)
unnamed: EPD_C4.2, J1.18
unnamed: EPD_C5.2, J1.19
unnamed: EPD_C6.2, J1.20
unnamed: EPD_C8.2, J1.22
unnamed: EPD_C10.2, J1.24
PREVGH: D5.1 (K), EPD_C7.2, J1.21
PREVGL: D4.2 (A), EPD_C9.2, J1.23
RESE: J1.3, Q3.2 (S), R3.2
RESE': R2.2, R3.1, SJ1.2
RESET: C5.1, IC1.1 (VOUT), RESET_BUTTON.3, RESET_BUTTON.4, R_RESET.2, U2.3 (EN)
RTC_RST: U2.16 (IO18), U3.4 (!RST)
RX: TP2.TP, U2.24 (RXD0/GPIO17)
SCK: D10.2, J1.13, J4.P5 (CLK), R6.1, TP8.TP, U1.6 (CLK), U2.6 (IO6)
SCL: J3.4, R2_PINH.1, SENSOR2.4 (SCK), U2.20 (IO22), U3.16 (SCL), U4.7 (SCL)
SDA: J3.3, R1_PINH.1, SENSOR2.3 (SDI), U2.19 (IO21), U3.15 (SDA), U4.8 (SDA)
SRC: C4.2, D5.2 (A), L1.1, Q3.3 (D)
SS_SD: D8.2, J4.P2 (CD/DAT3), R10.1, U2.4 (IO4)
TX: TP1.TP, U2.25 (TXD0/GPIO16)
USB_D+: D1.4 (I/O2_2), U2.14 (IO13)
USB_D-: D1.6 (I/O1_2), U2.13 (IO12)
VBAT: C2_BAT.1, MCP73831.3 (VBAT), Q1.3 (D), TP3.TP, U4.2 (CELL), U4.3 (VDD)
VBUS: C1_BAT.1, C4_USB.1, C5_USB.1, CHG_LED.A, D1.2 (GND), D2.2 (ANODE), MCP73831.4 (VIN), PMF.050.1.2, Q1.1 (G), R1_PWRUSB.2, TP14.TP
VRTC: C8.1, C10_SUPERCAP.2, R_CAPACITOR.1, U3.14 (VBAT)
VUSB: J2.A4, J2.A9, J2.B4, J2.B9, PMF.050.1.1

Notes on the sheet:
USB C connector & ESD protection
LDO Voltage Regulator
SD Card
Display type selector
E-Paper Drive Circuit
Li-Po Battery Charging Controller
ESP32 C6
E-Paper Display Header
EPD Power
Environmental Sensor BME 688
Voltage Supervisor + Reset & Boot / IO Button
Battery ChargeLevel
RTC Module DS3231SN
Test Pads
Qwiic / Stemma QT
SPI ESD Protection Lines
External NOR Flash 64MB

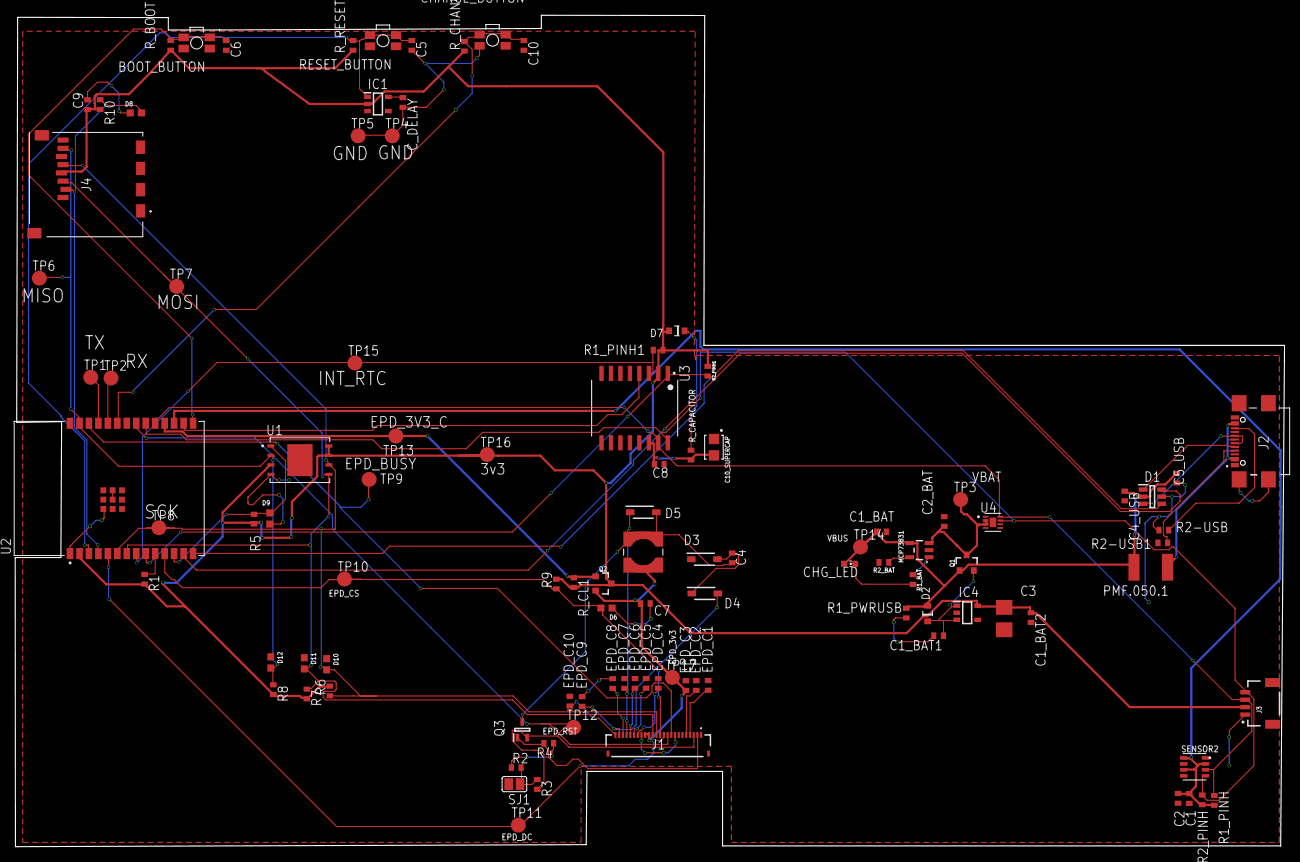
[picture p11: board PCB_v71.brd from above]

Board: 2 copper layers, 170.3 x 111.6 mm, 103 parts (0 on the bottom side), 55 nets.

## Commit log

2025-04-05 add project
    [Bill_of_materials.csv, PCB v62.brd, PnP_PCB v62_front.csv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]
2025-04-05 readme added. schema added
    [component_links.csv]
2025-04-06 Add OpenBook with battery connected
2025-04-06 OpenBook with connected battery
2025-04-06 Delete Mechanical/OpenBook Enclosure v16.rar
    Deleted rar. Added .zip file
2025-04-06 updated readme. added pins usage for esp32
2025-04-14 Updated PCB: Fixed values layer & thickness. Changed block scheme
    [PCB v62.brd, PCB_v71.brd]

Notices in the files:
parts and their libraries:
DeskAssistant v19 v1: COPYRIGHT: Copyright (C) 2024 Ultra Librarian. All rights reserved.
